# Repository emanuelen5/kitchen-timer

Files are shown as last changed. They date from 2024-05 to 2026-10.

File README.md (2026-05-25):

# Kitchen timer

We're building a Kitchen timer!
The project is heavily inspired by [REST: Kitchen timer by mkdxdx [Hackaday.io]](https://hackaday.io/project/194386-rest-kitchen-timer).

## Features

* ⏱️ Allows several timers to run in parallel
* ⚡ Is battery powered and power efficient
* 🔌 Charged by USB-C
* 💻 Programmable through the same USB port
* 🐍 Easter eggs

## Hardware

* Atmega328P as microcontroller
* Rotary encoder for setting the time
* 16x16 LED matrix as display
* 32 kHz crystal for accurate timekeeping
* Passive buzzer for beeping

See the bill of material in the KiCAD project for the full details.

### Mechanical components

Additionally, you will need the following mechanical components for the assembly:

Description                                               | Qty
--------------------------------------------------------- |-----
Hexagon Socket Button Head Screw ISO 7380-1 - M3 x 16     | 4
Hexagon Socket Button Head Screw ISO 7380-1 - M2 x        | 3
Brass Threaded Insert M3                                  | 4
Brass Threaded Insert M2                                  | 3
Hexagon Socket Button Head Screw ISO 7380-1 - M2 x        | 3
3.7V Lipo battery 1000mAh, 10x20x50mm, JST XH2.54 2 pin   | 1

### Manufacturing / gerber files

If you want to build the PCB yourself, you can download the latest release of Gerber files from Github: <https://github.com/emanuelen5/kitchen-timer/releases/latest>

### Enclosure

The .stl files are available in [./enclosure](./enclosure/) so you can 3D-print the enclosure yourself.

## Software

You can flash the program directly using the ISP header on the board if you want (the same procedure as flashing the bootloader, below). But it's more convenient to add the bootloader so you don't have to open up the enclosure for each software update. Then you can instead program it over the USB-C connector.

For that, you need the bootloader firmware and programmer software which you can download from <https://github.com/emanuelen5/kitchen-timer/releases/tag/bootloader-v1.2.0>.

### Bootloader

To flash the microcontroller with the bootloader, you need `avrdude`.
Avrdude 7.3 can be downloaded from <https://github.com/avrdudes/avrdude/releases/tag/v7.3>. Make sure to add it to your `PATH`.

Connect your programmer of choice to the 6-pin in-system programmer (ISP) connector: \
6-pin ISP header, as viewed from the top
<!--
Attribution:
["6- and 10-pin AVR ISP headers"](https://en.wikipedia.org/wiki/In-system_programming#/media/File:Isp_headers.svg)
by osiixy (2013-01-05), used under [CC BY 3.0](https://creativecommons.org/licenses/by/3.0/).
Adaptations: removed 10-pin header and some text; improved the contrast for dark
             mode.
-->

Then run the following command (replace `<programmer>` with your programmer of choice, like `usbtiny`):

```bash
# the bootloader.hex file needs to be in the current directory
avrdude -p atmega328p -c <programmer> -U flash:w:bootloader.hex:i \
  -U lfuse:w:0x62:m -U hfuse:w:0xD0:m -U efuse:w:0xFF:m
```

> [!TIP]
> Use `avrdude -c ?` to see which programmers are available

This flashes the bootloader and sets the required fuses for the bootloader.

After that you can disconnect the programmer and assemble the device.

### Programmer

Now that you have the bootloader on the device, you can use the USB-C cable for programming it by using the programmer application.

#### Dependencies

First you will need to install some packages that the programmer needs (files from <https://github.com/emanuelen5/kitchen-timer/releases/tag/bootloader-v1.2.0>).

```bash
pip install -r ./programmer/requirements.txt
```

You can now program the application onto the device through the bootloader!

### Upload firmware

Download the latest revision of the firmware (if you want to build it yourself, see [#Development](#development) below) from the releases <https://github.com/emanuelen5/kitchen-timer/releases>.

Connect the USB cable to the device, and then run

```bash
python3 ./programmer/programmer.py --hexfile firmware.hex
```

## Development

### Firmware

To build the firmware, you need `pio` which can be downloaded from <https://pypi.org/project/platformio/> or installed using `pip` (the official Package Installer for Python)

To build any of the environments, use the `pio` command, like

```bash
# builds the main application and puts it in .pio/builds/application/firmware.hex
pio run -e application
```

Then use the programmer to upload the firmware to the device.

## Background

Our kitchen timer is an iteration of [mkdxdx](https://hackaday.io/mkdxdx) project "REST: Kitchen timerREST: Kitchen timer". We wanted to keep the "dial" (rotate-to-set) concept and the 16x16 led matrix but do it with an ATmega328p and a custom PCB.
In the end we scrapped the dial since the design became too complicated, and settled on a simpler design.

### Motivation

Both [Erasmus Cedernaes](https://github.com/emanuelen5) and [Nicolas Perozzi](https://github.com/nperozzi) belong to [Stockholm Makerspace](https://www.makerspace.se/). On the same day, we messaged each other a link to mkdxdx project. We were very excited about building something that would be "practical" so we decided to team up and work on this together. Additionally, we share an interest in working with the AVR MCUs. This project is a nice blend of programming, electrical, mechanical, 3d printing, and design but, without feeling overwhelming.

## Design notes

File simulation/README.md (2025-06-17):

# Firmware simulation with Simavr

To connect to the simulator, do the following:

## Build Simavr simulation program

> [!NOTE]
> You must have built the bootloader firmware first!
> ```bash
> pio run -e bootloader
> ```

Then you can build the simulator

```bash
make
```

Run the simulator

```bash
build/simulator ../.pio/build/bootloader/firmware.hex
```

### Debug

If you pass the `-d` flag to the simulator, it will start a gdb debug server that you can attach to.

Then you can start a debug session with either
  1. From the VScode GUI <br>
     By using the launch configuration called "Attach to AVR gdbserver".
  2. From the command line <br>
     ```bash
     avr-gdb .pio/build/bootloader/firmware.elf
     ```
     And then run `target remote :1234` to attach to the debug session.

## License

This simulator uses Simavr, which is licensed as GPL-3.0. Thus, the whole
simulator is also licensed as GPL-3.0.

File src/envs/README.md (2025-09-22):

# Software

The software is divided into several "environments", similar to "sketches" in Arduino. They are used to test different aspects of the hardware individually, to make sure that the assembled hardware works as intended.

To build an environment, use `pio run -e <environment>`.

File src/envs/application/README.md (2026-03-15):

# Application Environment

## Purpose

Tests the full application layer with all hardware components working together: the LED matrix display, rotary encoder, push button, RTC, buzzer, and UART serial interface.

## Hardware Requirements

- 16×16 LED matrix driven by MAX72xx ICs via SPI (pins PB0, PB2, PB3, PB5)
- Rotary encoder connected to PD2 (channel A) and PD3 (channel B)
- Encoder push button connected to PD4 (SW_PIN)
- 32 kHz crystal connected to TOSC1/TOSC2 (for 1 Hz RTC tick)
- Passive buzzer connected to the buzzer output pin
- 3-LED binary counter connected to PC0–PC2
- UART serial port

## Expected Outcome

The kitchen timer application runs fully:
- Rotating the encoder sets the timer duration.
- A single button press starts or stops the active timer.
- A double press creates a new timer.
- A long press deletes the current timer.
- The LED matrix renders the timer state and counts down in real time.
- The buzzer sounds when a timer expires.
- Serial commands can be sent over UART to control and inspect the application.

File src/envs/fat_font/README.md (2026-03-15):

# Fat Font Environment

## Purpose

Tests the 16×16 LED matrix display by rendering digits using the "fat font" (6×7 pixels per character).

## Hardware Requirements

- 16×16 LED matrix driven by MAX72xx ICs via SPI (pins PB0, PB2, PB3, PB5)

## Expected Outcome

The LED matrix cycles through the digits 0–9, displaying each one for one second before moving to the next. The cycle repeats indefinitely.

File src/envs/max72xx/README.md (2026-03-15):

# MAX72xx Environment

## Purpose

Tests basic communication with the 16×16 LED matrix by toggling every pixel individually over SPI.

## Hardware Requirements

- 16×16 LED matrix driven by MAX72xx ICs via SPI (pins PB0, PB2, PB3, PB5)

## Expected Outcome

All 256 pixels light up one by one (left-to-right, top-to-bottom), and then turn off in the same order. The sequence repeats indefinitely, confirming that all pixels and the SPI link are working correctly.

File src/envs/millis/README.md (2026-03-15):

# Millis Environment

## Purpose

Tests the millisecond timer interrupt by incrementing the LED counter once per second.

## Hardware Requirements

- 3-LED binary counter connected to PC0–PC2

## Expected Outcome

The LED counter increments at a steady 1 Hz rate (once every 1000 ms), confirming that the timer interrupt is firing correctly.

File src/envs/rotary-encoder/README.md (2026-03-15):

# Rotary Encoder Environment

## Purpose

Tests the rotary encoder and its push button by reflecting the input on the LED counter.

## Hardware Requirements

- Rotary encoder connected to PD2 (channel A) and PD3 (channel B)
- Encoder push button connected to PD4 (SW_PIN)
- 3-LED binary counter connected to PC0–PC2

## Expected Outcome

- Rotating the encoder **clockwise** increments the LED counter.
- Rotating the encoder **counter-clockwise** decrements the LED counter.
- A **single press**, **double press**, or **long press** of the button resets the counter to 0.

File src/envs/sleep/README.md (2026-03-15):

# Sleep Environment

## Purpose

Tests the power-save sleep mode and the RTC (Timer2) 1-second interrupt used to wake the microcontroller.

## Hardware Requirements

- 32 kHz crystal connected to TOSC1/TOSC2 (for the Timer2 asynchronous clock)
- 3-LED binary counter connected to PC0–PC2

## Expected Outcome

The MCU enters power-save sleep and is woken up once per second by the RTC interrupt. On each wake cycle the LED counter increments (in the interrupt handler) and then decrements (back in the main loop), causing a visible oscillation on the LEDs that confirms the sleep/wake cycle is working correctly.

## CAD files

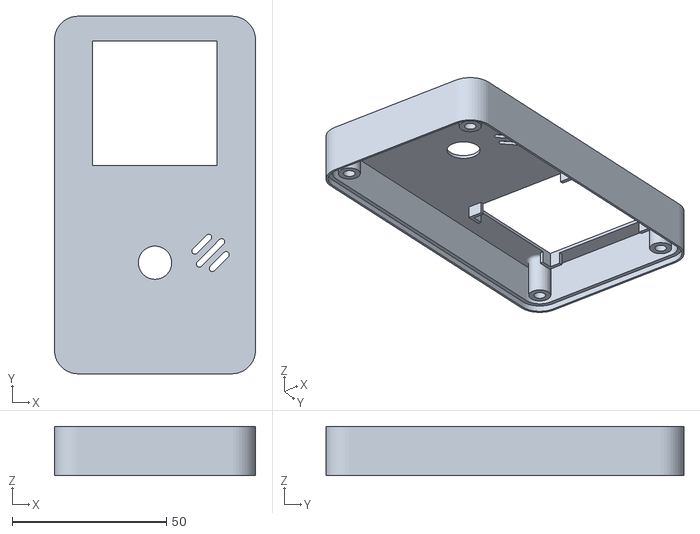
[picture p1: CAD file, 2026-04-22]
enclosure/kitchen_timer-top.stl
65.2 x 116.0 x 15.9

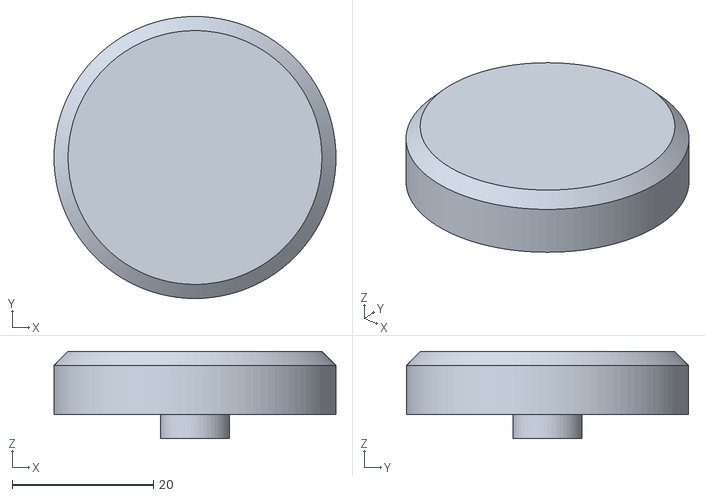
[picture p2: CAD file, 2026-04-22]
enclosure/kitchen_timer-knob.stl
40.0 x 40.0 x 12.4

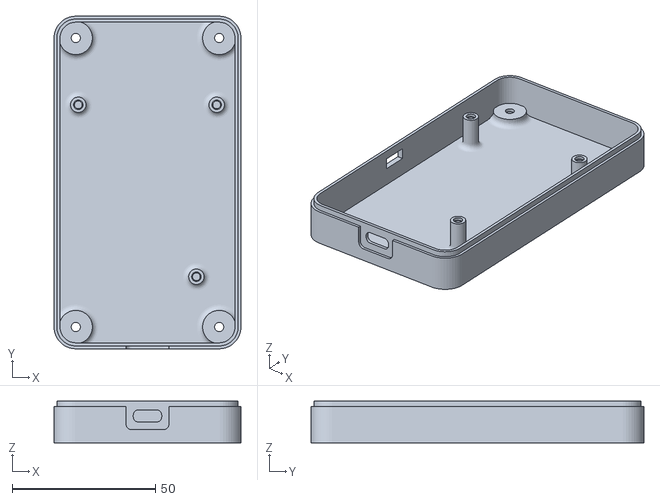
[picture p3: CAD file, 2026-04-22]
enclosure/kitchen_timer-base.stl
65.2 x 116.0 x 14.6

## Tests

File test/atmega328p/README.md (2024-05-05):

# Unit-testing on ATmega328P

This sub-directory contains tests that run on the ATmega328P natively.

## Hook up

To run the unit-tests, you will need to hook up a serial port to the microcontroller.

## Run the tests

To run it, you can use any of the `atmega328p` environments (see the [platformio.ini](../../platformio.ini) file). E.g.

```bash
pio test -e timer
```

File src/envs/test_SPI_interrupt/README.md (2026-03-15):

# Test SPI Interrupt Environment

## Purpose

Tests interrupt-driven SPI transfers by repeatedly sending two bytes over the SPI bus.

## Hardware Requirements

- SPI bus (pins PB2, PB3, PB5) with chip select on PB1 (pin 9)
- 3-LED binary counter connected to PC0–PC2 (optional, used for visual feedback)

## Expected Outcome

Every second, two bytes (`0xAA`) are queued and transferred via SPI using the interrupt handler. A logic analyzer or oscilloscope on the SPI lines will confirm that the transfers are happening correctly at 1 Hz.

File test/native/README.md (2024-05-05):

# Unit-testing on the native host

This sub-directory contains tests that can run on the native host, without any hardware connected.

## Run the tests

To run the tests, run the following.

```bash
pio test -e native
```

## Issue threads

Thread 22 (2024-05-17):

The alarm goes off when powered

nperozzi, 2024-05-17:
When you power the timer, the alarm goes off.

emanuelen5, 2024-05-27:
This does not happen for me. I tried:
1. Upload the "state_machine" sketch (revision 3bfb53817fe3359d4c499b4e5b061b1a1200c563)
2. Unplug and plug in the power again

emanuelen5, 2024-09-04:
We haven't seen this problem in a while, so let's close it for now.

Closed 2024-09-04.

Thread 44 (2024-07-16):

Create button library

nperozzi, 2024-07-16:
Yeah, it would have to be put into its own file. A file that just contains the functionality for pressing the button (not anything relating to the rotation). The button can be described as a state machine, and I think that would make it a lot easier to avoid the sneaky edge conditions :)

But either way, I think we should do this in a follow-up PR. This is definitely good enough for now!

I started a sketch on the state diagram, but it became a mess. I'll have to get back to it. Leaving it here for now:

```mermaid
stateDiagram-v2
    state if_state1 <<choice>>
    state if_state2 <<choice>>

    [*] --> EvaluateSinglePress: PRESS
    EvaluateSinglePress --> SinglePress: [time_since_init < 500 ms] DEPRESS
    EvaluateSinglePress --> LongPress: [time of state > 2000 ms]

    state EvaluateSinglePress {
        [*] --> S1_Wait: [time_since_init <= 500 ms] DEPRESS
    }
    EvaluateSinglePress --> if_state1
    if_state1 --> SinglePress: [time_since_init > 500ms]
    if_state1 --> EvaluateDoublePress: [time_since_init <= 500ms]

    state EvaluateDoublePress {
        [*] --> S2_Wait1: [time_since_init <= 500ms] PRESS
        S2_Wait1 --> S2_Wait2: [time_since_init <= 500ms] DEPRESS
    }
    EvaluateDoublePress --> if_state2
    if_state2 --> DoublePress: [time_since_init <= 500ms] PRESS
    if_state2 --> SinglePress: [time_since_init > 500 ms] PRESS
    if_state2 --> [*]: [time_since_init > 500 ms] DEPRESS

    SinglePress --> [*]
    DoublePress --> [*]
    LongPress --> [*]
```

_Originally posted by @emanuelen5 in https://github.com/emanuelen5/kitchen-timer/pull/41#discussion_r1678366517_

Closed 2024-10-06.

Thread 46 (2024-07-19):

Application Layer

nperozzi, 2024-07-19:
The idea of the `timer_t` class was that it should be as simple as possible. That way we wouldn't need to update it, and its unit tests would still hold.

With more state (variables) added to the object, it becomes more complex and more difficult to test. The tests we've already created do not help as much. And the object doesn't do **only** what was initially intended anymore (just keeping time). This is a code smell:
> Large Class - Class trying to do too much and has too many instance variables[^1]

[^1]: https://refactoring.guru/smells/large-class

I think it would be wiser to try to add another layer of state, an application state:

```mermaid
classDiagram
    class application_t {
        state_machine_t state_machines[MAX_TIMERS]
        uint8_t current_timer_index
    }
    application_t --> state_machine_t

    class state_machine_t {
        state_t state
        timer_t timer
        uint16_t millis_of_last_transition
    }
    state_machine_t --> timer_t

    class timer_t {
        uint16_t original_time
        uint16_t current_time
    }

```

The application would manage what timer is active, and what to show on the display. Adding an abstraction like that even makes it easier to test!

_Originally posted by @emanuelen5 in https://github.com/emanuelen5/kitchen-timer/pull/42#discussion_r1678294955_

nperozzi, 2024-07-19:
After a failed attempt to write the application layer, we agreed it would be best to decide how it should look before I start writing some code 😅 .
This issue aims to do that: agree on what the application layer should do and what the structure should look like before I start writing.

nperozzi, 2024-07-19:
From our conversation yesterday, this is what I understand:
### What should that application layer do?
* Handling the display logic: It decides what state machine is displayed at a given time.
* Decides which state machine gets affected by each event. Example 1: a SINGLE_PRESS would affect only the state machine displayed (current_state_machine) but not the others. Example 2: the SECON_TICK affects all state machines in a RUNNING state.

### Other considerations:
* The application layer is not another state machine. It does not handle states.
* When a state machine goes into state RINGING, it can have a flag that informs the application that it needs to become the current state machine and be displayed.
* The debugging `printf` can remain in the state machines. If a variable within the application struct is needed in the printf (for example `current_state_machine_index`, the application can be passed to the state_machine as a call-back ( following the principle of  "Dependency Inversion")
* Keep the "Law of Demeter" in mind: "Objects only talk directly to their immediate objects" Otherwise, to retrieve information, a function needs to be created.

While writing this, I think how much I may have misinterpreted 🤣.

Closed 2024-08-17.

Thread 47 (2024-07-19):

README files

nperozzi, 2024-07-19:
NOTE: Now that I know that we can discuss topics as Issues, I will go nuts with the issues 😀 !!!

This issue is to discuss how to structure the README files. We talked about it once but I have little space in my memory so I forgot 😓 .

This is how I think we can structure README files (Largely inspired in [kinx project](https://github.com/kinx-project/kint?tab=readme-ov-file) and ChatGPT suggestions):
## Main README:
1. Introduction:
    1. Quick Description
    1.  Motivation
    1.  Features
1. Table of content
1. Software
     1. Description: Brief overview of the software component.
     1. Requirements: Dependency from software versions or external libraries
     1. How to set up the toolchain?
     1. How to install the firmware?
     1. Debugging instructions
1. Hardware
     1. Description: Overview of the hardware components
     2. Hardware BOM
     3. Schematics
     4. Assembly instructions
1. Mechanical
     1. Description: Overview of mechanical components and design.
     2. CAD Files: Links to or images of CAD designs.
     3. Assembly Instructions: Instructions for assembling the mechanical parts.
1. Usage
     1. Power on
     2. Setting timers
     3. ...
     4. Other features
     5. Command prompt

## README file in each library folder:
1. Title
2. What is this library used for?
3. API Reference: Description of functions and objects provided by the library.
4. Configuration: Any configuration variable that the library supports (ex: max number of state machines)
5. Usage: How to implement the library in a generic main file (maybe an example too)

nperozzi, 2024-07-22:
One more note: If we have a README file for each library, shouldn´t we separate the libraries into folders?

emanuelen5, 2024-07-23:
> One more note: If we have a README file for each library, shouldn´t we separate the libraries into folders?

I don't think we need a README for each library. Most of them are easy to understand since they have code that references them. However, I do think that we should explain the sketches / envs, since we need to describe what the minimal setup is required for testing each one of them, and what the expected outcome is.

As a note: We had the libraries in separate folders a while back. But, in 6de6451610f1a4197224e9a18b1edc7b60533f7a I decided that we didn't really benefit from having two files in each folder, with the same name (like `lib/timer/timer.cpp` and `lib/timer/timer.h`).

nperozzi, 2024-07-23:
Understood: no README for libraries but yes for the sketches/envs. 👍😄

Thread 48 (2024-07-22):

SPI communication between display and MCU

nperozzi, 2024-07-22:
I want to make the communication between the display and the MCU SPI since MAX7219 supports it. I believe we talked about it and you agreed. Unfortunately, I believe that it will require some changes in the max72xx library and display library that you already created.
I have started a branch to work on this: [SPI_Max72xx library](https://github.com/emanuelen5/kitchen-timer.git)
This is how I am thinking about it:
* __SPI library__: just to initialize the SPI and a function to transmit a byte.
* __max72xx library__: to initialize the max7219 and functions to write to the registers

With the above, I believe this issues can be closed but, it got me thinking on the following two libraries. I can open a separate issue for this part, if that is ok.
* __display library__: to initialize and write to all max7219. This library should include a function that parses the patterns (numbers and other patterns) to the display.
* __patterns library__: to store the different patterns that can be displayed.

emanuelen5, 2024-07-23:
Just to clarify, it is already using SPI to the display, just not the hardware block in the MCU. By switching to this, we can free up lots of CPU cycles, which is great!

Related PR note: https://github.com/emanuelen5/kitchen-timer/pull/29#issue-2317580666
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

> [^1]: https://forum.arduino.cc/t/spi-miso-mosi-used-in-sketch-possible-to-re-program-via-external-programmer/492461/8
> [^2]: https://onlinedocs.microchip.com/pr/GUID-EEA42155-A873-46B4-9500-D88617041B0B-en-US-2/index.html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
> [^3]: https://onlinedocs.microchip.com/pr/GUID-EEA42155-A873-46B4-9500-D88617041B0B-en-US-2/index.html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

nperozzi, 2024-07-23:
I think I am stepping on your toes here 😟 . Last night I basically re-wrote your max72xx library when maybe it would suffice with some changes (see [SPI_Max72xx library](https://github.com/emanuelen5/kitchen-timer.git)).
How would you like me to proceed here? Maybe I should let you add the hardware SPI block yourself?

nperozzi, 2024-08-17:
When possible, we should take a look at your max72xx and display libraries. I don´t understand what is happening there.

I am also not sure what you mean by the "SPI block". I am guessing that you mean that the max7219 is receiving SPI but the message is generated by the MCU instead of using the microcontroller´s SPI functionality.

Closed 2024-10-08.

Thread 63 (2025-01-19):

Will the bootloader using the UART interfere with the serial communication commands?

nperozzi, 2025-01-19:

emanuelen5, 2025-01-19:
They will not interfere :) The bootloader will only occupy the serial port until the microcontroller has booted the regular application. Then the regular application will take over the serial port.

Closed 2025-01-19.

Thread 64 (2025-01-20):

The UART Module only provides 500mA.

nperozzi, 2025-01-20:
While working on the schematic, I noticed that the UART Module, has a fuse that prevents over-current and only allows 500mA of current. That could be enough to do battery charging but I fear it might not be enough to power the display when the USB is connected to power.

I want some help reviewing power consumption calculations to confirm if 500mA will not be enough.

If it is not enough, an option could be to discard the UART Module and add the USB-C and USB-to-TTL chip directly on our PCB. That way we could draw as much current from the USB as it can supply. It will be more complex though. Do you have better ideas?

nperozzi, 2025-01-22:
After some investigation, it seems that drawing more than 500mA out of a USB port is not a good idea. Doing so can damage the USB host (aka the USB HW in the laptop).
We still have to answer the question: Do we need more than 500mA?

nperozzi, 2025-07-31:
For an average current draw, we need about 86mA. At current pick, we would be drawing about 1300mA, but the UART module will simply not allow it, and the display would light up at not full brightness.

I am closing this issue.

Closed 2025-07-31.

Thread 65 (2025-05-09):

What should be the track width and the via size?

nperozzi, 2025-05-09:
# Track width:
I used the KiCad Calculator Tool. For an avg. current draw of 85.5mA, as calculated in the schematic (sheet Battery Power Requirements), the signal tracks' width should be 9.69mils (~10mils = 0.254mm).

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

For the power nets, I used the peak current draw of 1278.5mA. In this case, the power track width should be at least 16.9mils (~17mil = 0,43mm).

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

#Via size
We are using a via size of 0.7mm in diameter and 0.3mm hole. We got this value from "Philip´s Lab" Youtube Channel.
We used the KiCad Calculator Tool. The resistance, voltage drop, and power loss seem negligible for this via size.

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

nperozzi, 2025-05-09:
- [ ]  We need to adjust the track size for power.

emanuelen5, 2025-05-10:
Great! So neither of the tracks are under-dimensioned as it is. Having a larger power track is also better, even if we would make do with a smaller one.

> We are using a via size of 0.7mm in diameter and 0.3mm hole

We're actually using 0.8 mm since the DRC didn't like the annealing width when it was set to 0.7:

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

Sounds like we don't have to make any adjustments?

emanuelen5, 2025-05-10:
It looks like you used 855mA in your calculation, not 85.5?

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

nperozzi, 2025-05-11:
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

You are right. It was a mistake. Here is the calculation with 85.5mA. It is way smaller in width, so we are good anyway. :)

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

Closed 2025-07-31.

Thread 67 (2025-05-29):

How to make the timers be in RING state no more than a fixed period of timer (maybe just 20 secs)?

nperozzi, 2025-05-29:
Do we need another state?
Could we use the TIMEOUT state?

nperozzi, 2025-07-31:
We solved this by tracking the time that the timer has been in RINGING state, in the `service_state_machine()` function.

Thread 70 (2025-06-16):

Test poin traces is too thin

nperozzi, 2025-06-16:
The +5V test point should have a thicker trace.

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

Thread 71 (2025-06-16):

UART USB powers the MCU with the power switch OFF

nperozzi, 2025-06-16:
When connecting the UART to USB, the MCU appears to receive power even though the power switch is off.

State when the power switch is OFF:
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

State when the power switch is ON:

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

emanuelen5, 2025-07-05:
The MCU becomes back-powered through the RX pin that the USB-UART device drives high when it's idle. See this post for a potential solution: https://electronics.stackexchange.com/a/616357

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

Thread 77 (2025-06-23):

Hole H7 is too close to the trace.

nperozzi, 2025-06-23:
As it is, it works, but the trace is dangerously close to the hole. We should consider moving the hole.

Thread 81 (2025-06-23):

Disabling interrupts durign rtc ISR rutine.

nperozzi, 2025-06-23:
When we disable interrupts on the rtc ISR routine, the program (as seen on the display) does not glitch. If we take the sei() away, it glitches. We do not know why.
Adding "nop()"s does not seem to fix it.

emanuelen5, 2025-07-31:
Yes, let's do that

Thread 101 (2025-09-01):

The device resets when it is disconnected from the computer.

nperozzi, 2025-09-01:

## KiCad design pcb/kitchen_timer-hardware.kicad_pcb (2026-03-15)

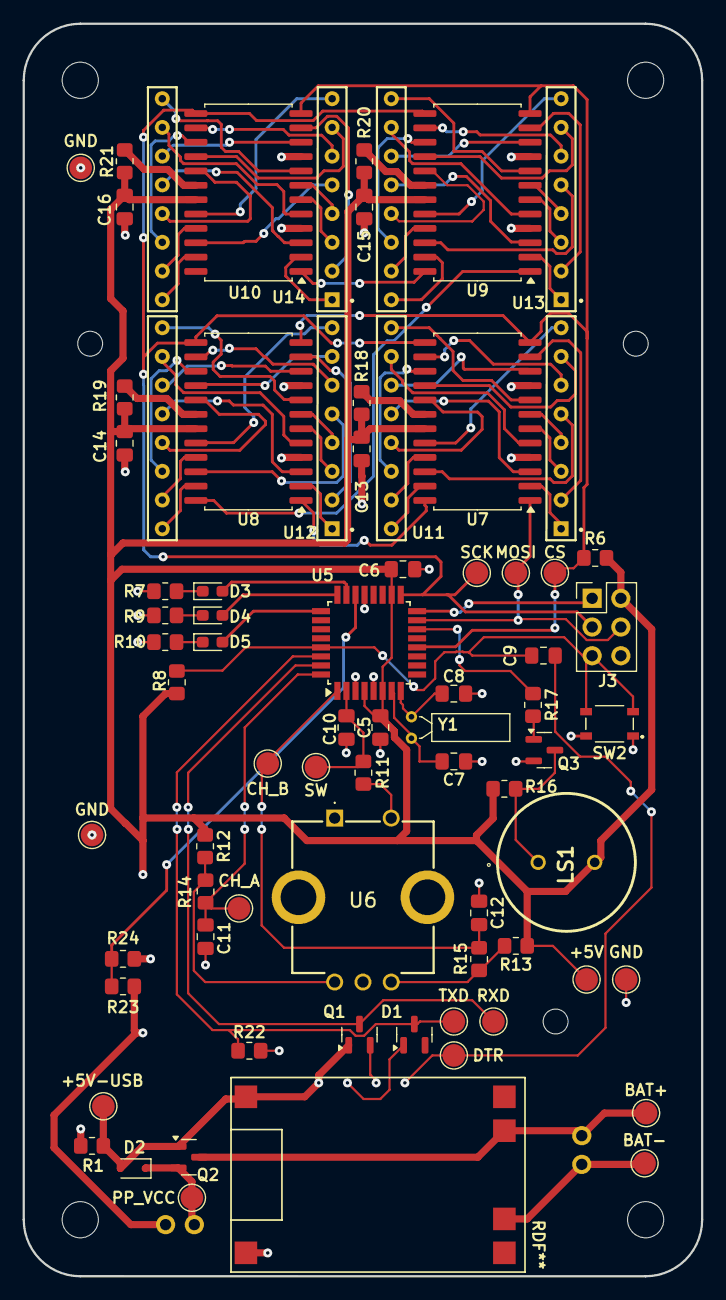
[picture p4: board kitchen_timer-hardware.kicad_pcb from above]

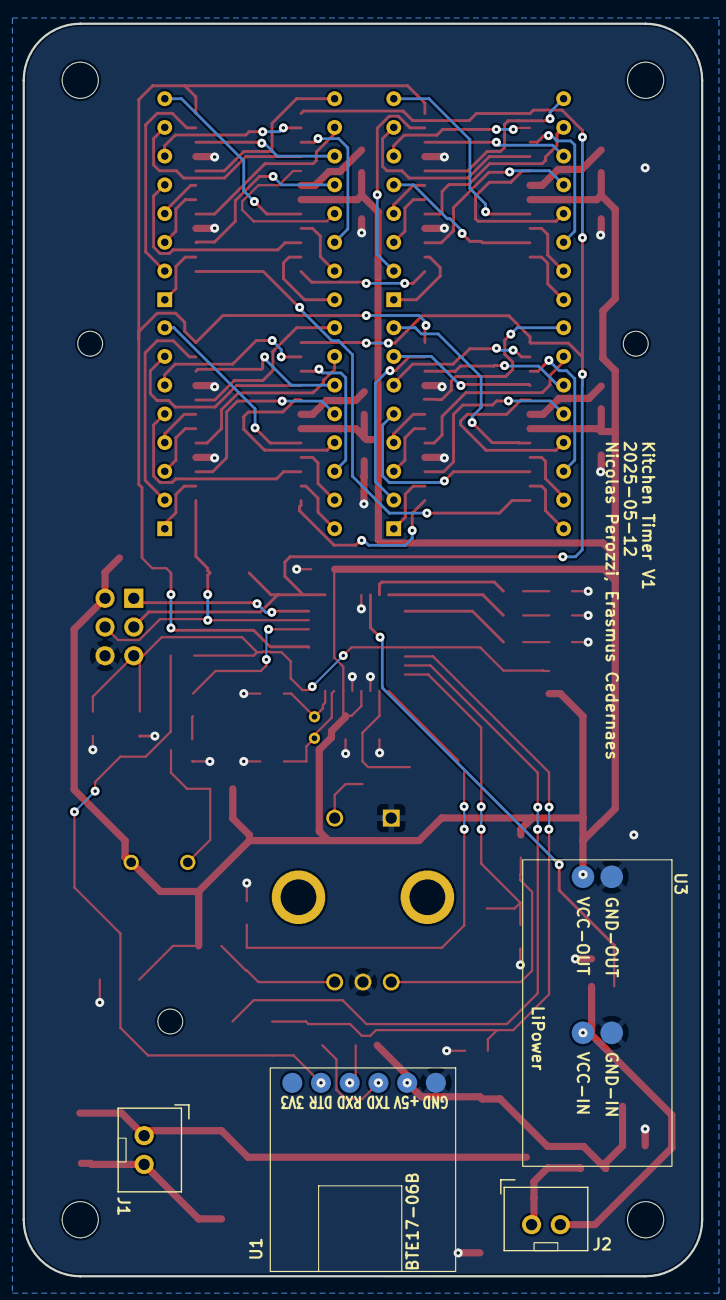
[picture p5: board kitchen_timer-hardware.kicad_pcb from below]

Board: 2 copper layers, 60.0 x 110.8 mm, 83 parts (4 on the bottom side), 106 nets.

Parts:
C5, C6, C9, C13, C14, C15, C16: 100nF; C_0805_2012Metric_Pad1.18x1.45mm_HandSolder
C7, C8: 22pF; C_0805_2012Metric_Pad1.18x1.45mm_HandSolder
C10, C11, C12: 10nF; C_0805_2012Metric_Pad1.18x1.45mm_HandSolder
D1: BAS40; SOT-23
D2: PMEG4010CEJ; D_SOD-323F
D3, D4, D5: Red test LED; LED_0603_1608Metric_Pad1.05x0.95mm_HandSolder
H1, H2, H7: MountingHole; MountingHole_2.2mm_M2
H3, H4, H5, H6: MountingHole; MountingHole_3.2mm_M3
J1: Conn_01x02; JST_XH_1x02_P2.54mm_Vertical
J2: Conn_01x02_Pin; JST_XH_1x02_P2.54mm_Vertical
J3: AVR-ISP-6; PinHeader_2x03_P2.54mm_Vertical
LS1: PS1240P02CT3; PS1240P02BT
Q1: JSM2302; SOT-23
Q2: IRLML6402; SOT-23
Q3: MMBT3904; MMBT3904 (SOT-23)
R1, R6, R8, R11, R12, R13, R14, R15, R22: 10k; R_0805_2012Metric_Pad1.20x1.40mm_HandSolder
R7, R9, R10, R16, R17: 1k; R_0805_2012Metric_Pad1.20x1.40mm_HandSolder
R18, R19, R20, R21: 62K; R_0805_2012Metric_Pad1.20x1.40mm_HandSolder
R23: 3.3M; R_0805_2012Metric_Pad1.20x1.40mm_HandSolder
R24: 1M; R_0805_2012Metric_Pad1.20x1.40mm_HandSolder
SW2: SKRPACE010; SW_SKRPACE010
TP1: MOSI; TestPoint_Pad_D2.0mm
TP2: TXD; TestPoint_Pad_D2.0mm
TP3: SCK; TestPoint_Pad_D2.0mm
TP4: RXD; TestPoint_Pad_D2.0mm
TP5: CS; TestPoint_Pad_D2.0mm
TP6: DTR; TestPoint_Pad_D2.0mm
TP7: +5V-USB; TestPoint_Pad_D2.0mm
TP8, TP14, TP15: GND; TestPoint_Pad_D2.0mm
TP9: CH_A; TestPoint_Pad_D2.0mm
TP10: CH_B; TestPoint_Pad_D2.0mm
TP11: SW; TestPoint_Pad_D2.0mm
TP12: +5V; TestPoint_Pad_D2.0mm
TP13: PP_VCC; TestPoint_Pad_D2.0mm
TP16: BAT+; TestPoint_Pad_D2.0mm
TP17: BAT-; TestPoint_Pad_D2.0mm
U1: CH340E UART Module; CH340E_UART_BREAKOUT
U2: TP4056 breakout; TP4056_BREAKOUT
U3: SparkFun_LiPower
U5: ATMEGA328P-AU; TQFP-32_7x7mm_P0.8mm
U6: PEC11R-4215F-S0024; PEC11R4215FS0024
U7, U8, U9, U10: MAX7219; SOIC-24W_7.5x15.4mm_P1.27mm
U11, U12, U13, U14: KWM-20882CUYB
Y1: Crystal-32kHz; Crystal_C26-LF_D2.1mm_L6.5mm_Horizontal

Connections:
+5V: C5.1, C6.1, C13.1, C14.1, C15.1, C16.1, J3.2 (VCC), LS1.2, R6.1, R8.1, R12.1, R13.1, R16.2, R18.1, R19.1, R20.1, R21.1, TP12.1, U3.3 (VCC_OUT), U5.4 (VCC), U5.6 (VCC), U5.18 (AVCC), U7.19 (V+), U8.19 (V+), U9.19 (V+), U10.19 (V+)
/+5V Boost Converter/BAT_VOLT: R23.2, R24.1, U5.22 (ADC7)
/+5V Boost Converter/PP_VCC: D2.1 (K), J2.1, Q2.2 (S), TP13.1
/BMS & Power Path/+5V-USB: D2.2 (A), Q1.1 (G), Q2.1 (G), R1.2, TP7.1, U1.5 (+5V), U2.1 (IN+)
/BMS & Power Path/BAT+: J1.1, Q2.3 (D), TP16.1, U2.4 (B+)
/BMS & Power Path/BAT-: J1.2, TP17.1, U2.5 (B-)
/LED Matrices Drivers/CS: R6.2, TP5.1, U5.12 (PB0), U7.12 (LOAD), U8.12 (LOAD), U9.12 (LOAD), U10.12 (LOAD)
/LED Matrices Drivers/MOSI: J3.4 (MOSI), TP1.1, U5.15 (PB3), U7.1 (DIN)
/LED Matrices Drivers/Mat1A.DIG_0: U7.2 (DIG_0), U11.01 (R1)
/LED Matrices Drivers/Mat1A.DIG_1: U7.11 (DIG_1), U11.02 (R2)
/LED Matrices Drivers/Mat1A.DIG_2: U7.6 (DIG_2), U11.03 (R3)
/LED Matrices Drivers/Mat1A.DIG_3: U7.7 (DIG_3), U11.04 (R4)
/LED Matrices Drivers/Mat1A.DIG_4: U7.3 (DIG_4), U11.12 (R5)
/LED Matrices Drivers/Mat1A.DIG_5: U7.10 (DIG_5), U11.11 (R6)
/LED Matrices Drivers/Mat1A.DIG_6: U7.5 (DIG_6), U11.10 (R7)
/LED Matrices Drivers/Mat1A.DIG_7: U7.8 (DIG_7), U11.09 (R8)
/LED Matrices Drivers/Mat1A.SEG_A: U7.14 (SEG_A), U11.06 (C2)
/LED Matrices Drivers/Mat1A.SEG_B: U7.16 (SEG_B), U11.07 (C3)
/LED Matrices Drivers/Mat1A.SEG_C: U7.20 (SEG_C), U11.08 (C4)
/LED Matrices Drivers/Mat1A.SEG_D: U7.23 (SEG_D), U11.16 (C5)
/LED Matrices Drivers/Mat1A.SEG_DP: U7.22 (SEG_DP), U11.05 (C1)
/LED Matrices Drivers/Mat1A.SEG_E: U7.21 (SEG_E), U11.15 (C6)
/LED Matrices Drivers/Mat1A.SEG_F: U7.15 (SEG_F), U11.14 (C7)
/LED Matrices Drivers/Mat1A.SEG_G: U7.17 (SEG_G), U11.13 (C8)
/LED Matrices Drivers/Mat1B.DIG_0: U8.2 (DIG_0), U12.01 (R1)
/LED Matrices Drivers/Mat1B.DIG_1: U8.11 (DIG_1), U12.02 (R2)
/LED Matrices Drivers/Mat1B.DIG_2: U8.6 (DIG_2), U12.03 (R3)
/LED Matrices Drivers/Mat1B.DIG_3: U8.7 (DIG_3), U12.04 (R4)
/LED Matrices Drivers/Mat1B.DIG_4: U8.3 (DIG_4), U12.12 (R5)
/LED Matrices Drivers/Mat1B.DIG_5: U8.10 (DIG_5), U12.11 (R6)
/LED Matrices Drivers/Mat1B.DIG_6: U8.5 (DIG_6), U12.10 (R7)
/LED Matrices Drivers/Mat1B.DIG_7: U8.8 (DIG_7), U12.09 (R8)
/LED Matrices Drivers/Mat1B.SEG_A: U8.14 (SEG_A), U12.06 (C2)
/LED Matrices Drivers/Mat1B.SEG_B: U8.16 (SEG_B), U12.07 (C3)
/LED Matrices Drivers/Mat1B.SEG_C: U8.20 (SEG_C), U12.08 (C4)
/LED Matrices Drivers/Mat1B.SEG_D: U8.23 (SEG_D), U12.16 (C5)
/LED Matrices Drivers/Mat1B.SEG_DP: U8.22 (SEG_DP), U12.05 (C1)
/LED Matrices Drivers/Mat1B.SEG_E: U8.21 (SEG_E), U12.15 (C6)
/LED Matrices Drivers/Mat1B.SEG_F: U8.15 (SEG_F), U12.14 (C7)
/LED Matrices Drivers/Mat1B.SEG_G: U8.17 (SEG_G), U12.13 (C8)
/LED Matrices Drivers/Mat2A.DIG_0: U9.2 (DIG_0), U13.01 (R1)
/LED Matrices Drivers/Mat2A.DIG_1: U9.11 (DIG_1), U13.02 (R2)
/LED Matrices Drivers/Mat2A.DIG_2: U9.6 (DIG_2), U13.03 (R3)
/LED Matrices Drivers/Mat2A.DIG_3: U9.7 (DIG_3), U13.04 (R4)
/LED Matrices Drivers/Mat2A.DIG_4: U9.3 (DIG_4), U13.12 (R5)
/LED Matrices Drivers/Mat2A.DIG_5: U9.10 (DIG_5), U13.11 (R6)
/LED Matrices Drivers/Mat2A.DIG_6: U9.5 (DIG_6), U13.10 (R7)
/LED Matrices Drivers/Mat2A.DIG_7: U9.8 (DIG_7), U13.09 (R8)
/LED Matrices Drivers/Mat2A.SEG_A: U9.14 (SEG_A), U13.06 (C2)
/LED Matrices Drivers/Mat2A.SEG_B: U9.16 (SEG_B), U13.07 (C3)
/LED Matrices Drivers/Mat2A.SEG_C: U9.20 (SEG_C), U13.08 (C4)
/LED Matrices Drivers/Mat2A.SEG_D: U9.23 (SEG_D), U13.16 (C5)
/LED Matrices Drivers/Mat2A.SEG_DP: U9.22 (SEG_DP), U13.05 (C1)
/LED Matrices Drivers/Mat2A.SEG_E: U9.21 (SEG_E), U13.15 (C6)
/LED Matrices Drivers/Mat2A.SEG_F: U9.15 (SEG_F), U13.14 (C7)
/LED Matrices Drivers/Mat2A.SEG_G: U9.17 (SEG_G), U13.13 (C8)
/LED Matrices Drivers/Mat2B.DIG_0: U10.2 (DIG_0), U14.01 (R1)
/LED Matrices Drivers/Mat2B.DIG_1: U10.11 (DIG_1), U14.02 (R2)
/LED Matrices Drivers/Mat2B.DIG_2: U10.6 (DIG_2), U14.03 (R3)
/LED Matrices Drivers/Mat2B.DIG_3: U10.7 (DIG_3), U14.04 (R4)
/LED Matrices Drivers/Mat2B.DIG_4: U10.3 (DIG_4), U14.12 (R5)
/LED Matrices Drivers/Mat2B.DIG_5: U10.10 (DIG_5), U14.11 (R6)
/LED Matrices Drivers/Mat2B.DIG_6: U10.5 (DIG_6), U14.10 (R7)
/LED Matrices Drivers/Mat2B.DIG_7: U10.8 (DIG_7), U14.09 (R8)
/LED Matrices Drivers/Mat2B.SEG_A: U10.14 (SEG_A), U14.06 (C2)
/LED Matrices Drivers/Mat2B.SEG_B: U10.16 (SEG_B), U14.07 (C3)
/LED Matrices Drivers/Mat2B.SEG_C: U10.20 (SEG_C), U14.08 (C4)
/LED Matrices Drivers/Mat2B.SEG_D: U10.23 (SEG_D), U14.16 (C5)
/LED Matrices Drivers/Mat2B.SEG_DP: U10.22 (SEG_DP), U14.05 (C1)
/LED Matrices Drivers/Mat2B.SEG_E: U10.21 (SEG_E), U14.15 (C6)
/LED Matrices Drivers/Mat2B.SEG_F: U10.15 (SEG_F), U14.14 (C7)
/LED Matrices Drivers/Mat2B.SEG_G: U10.17 (SEG_G), U14.13 (C8)
/LED Matrices Drivers/SCK: J3.3 (SCK), TP3.1, U5.17 (PB5), U7.13 (CLK), U8.13 (CLK), U9.13 (CLK), U10.13 (CLK)
/Microcontroller/DTR: C9.1, TP6.1, U1.2 (DTR)
/Microcontroller/ENCODER_CH_A: C11.1, R14.2, TP9.1, U5.32 (PD2)
/Microcontroller/ENCODER_CH_B: C12.1, R15.2, TP10.1, U5.1 (PD3)
/Microcontroller/MCU_RXD: D1.3 (K), R22.1, TP2.1, U5.30 (PD0)
/Microcontroller/MCU_TXD: Q1.3 (D), TP4.1, U5.31 (PD1)
/Microcontroller/MISO: J3.1 (MISO), U5.16 (PB4)
/Microcontroller/RESET: C9.2, J3.5 (~RST), R8.2, SW2.3, SW2.4, U5.29 (~RESET/PC6)
/Microcontroller/SPEAKER: R17.1, U5.14 (PB2)
/Microcontroller/SW: C10.1, R11.2, TP11.1, U5.2 (PD4)
/Microcontroller/TEST_LED1: D3.2 (A), U5.23 (PC0)
/Microcontroller/TEST_LED2: D4.2 (A), U5.24 (PC1)
/Microcontroller/TEST_LED3: D5.2 (A), U5.25 (PC2)
/Microcontroller/XTAL1: C7.1, U5.7 (XTAL1/PB6), Y1.1
/Microcontroller/XTAL2: C8.1, U5.8 (XTAL2/PB7), Y1.2 (CRYSTAL_2)
GND: C5.2, C6.2, C7.2, C8.2, C10.2, C11.2, C12.2, C13.2, C14.2, C15.2, C16.2, J3.6 (GND), Q3.2 (E), R1.1, R7.2, R9.2, R10.2, R22.2, R24.2, SW2.1, SW2.2, TP8.1, TP14.1, TP15.1, U1.6 (GND), U2.2 (IN-), U3.2 (GND-IN), U3.4 (GND_OUT), U5.3 (GND), U5.5 (GND), U5.21 (GND), U6.1 (COM), U6.C1 (COMMON), U7.4 (GND), U7.9 (GND), U8.4 (GND), U8.9 (GND), U9.4 (GND), U9.9 (GND), U10.4 (GND), U10.9 (GND)
unnamed: D1.1 (A), U1.4 (TXD)
unnamed: D3.1 (K), R7.1
unnamed: D4.1 (K), R9.1
unnamed: D5.1 (K), R10.1
unnamed: Q1.2 (S), U1.3 (RXD)
unnamed: Q3.1 (B), R17.2
unnamed: LS1.1, Q3.3 (C), R16.1
unnamed: R12.2, R14.1, U6.A1 (CHANNEL_A)
unnamed: R13.2, R15.1, U6.B1 (CHANNEL_B)
unnamed: R11.1, U6.2 (NO)
unnamed: U7.24 (DOUT), U8.1 (DIN)
unnamed: R18.2, U7.18 (ISET)
unnamed: U8.24 (DOUT), U9.1 (DIN)
unnamed: R19.2, U8.18 (ISET)
unnamed: R20.2, U9.18 (ISET)
unnamed: U9.24 (DOUT), U10.1 (DIN)
unnamed: R21.2, U10.18 (ISET)
PP_VCC_after_switch: J2.2, R23.1, U3.1 (VCC_IN)

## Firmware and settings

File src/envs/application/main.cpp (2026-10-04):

#include <avr/io.h>
#include <avr/interrupt.h>
#include <avr/pgmspace.h>

#include "util.h"
#include "rtc.h"
#include "millis.h"
#include "uint8-queue.h"
#include "UART.h"
#include "serial_commands.h"
#include "reboot.h"
#include "led-counter.h"

#include "max72xx.h"
#include "avr_button.h"
#include "rotary-encoder.h"
#include "application.h"
#include "render.h"

uint8_queue_t eventQueue;
static const uint8_t queue_buffer_size = 8;
uint8_t event_queue_buffer[queue_buffer_size];

application_t app;
state_machine_t* active_sm = &app.state_machines[app.current_active_sm];

void init_watchdog(void) __attribute__((naked)) __attribute__((section(".init3"))); //desables watchdog before main().

void rotation_cb(rotation_dir_t dir, rotation_speed_t speed, bool held_down)
{
    event_t event;
    if (held_down && dir == cw)
        event = CW_PRESSED_ROTATION;
    else if (held_down && dir == ccw)
        event = CCW_PRESSED_ROTATION;
    else if (!held_down && dir == cw && speed == fast)
        event = CW_ROTATION_FAST;
    else if (!held_down && dir == cw)
        event = CW_ROTATION;
    else if (!held_down && dir == ccw && speed == fast)
        event = CCW_ROTATION_FAST;
    else if (!held_down && dir == ccw)
        event = CCW_ROTATION;

    add_to_queue(&eventQueue, event);
}

void on_single_press(void)
{
    add_to_queue(&eventQueue, SINGLE_PRESS);
}

void on_double_press(void)
{
    add_to_queue(&eventQueue, DOUBLE_PRESS);
}

void on_long_press(void)
{
    add_to_queue(&eventQueue, LONG_PRESS);
}

void second_tick_cb(void)
{
    add_to_queue(&eventQueue, SECOND_TICK);
}


void on_line_received(char *line)
{
    handle_command(line, &command_callbacks, &app);
}

int main()
{
    AvrButton button(&on_single_press, &on_double_press, &on_long_press, &rotation_cb);

    init_hw_UART(on_line_received);
    init_hw_timer2_to_1s_interrupt(&second_tick_cb);
    init_hw_millis();
    init_hw_led_counter();
    init_hw_max72xx();
    init_queue(&eventQueue, event_queue_buffer, queue_buffer_size);
    init_hw_rotary_encoder(button);
    init_application(&app);
    max72xx_set_intensity(app.brightness);
    sei();

    init_max72xx();
    while (true)
    {
        for (uint8_t count = UART_received_char_count(); count != 0; count--)
        {
            service_receive_UART();
        }

        button.service();

        dequeue_return_t event;
        while ((event = dequeue(&eventQueue)).is_valid)
        {
            application_handle_event(&app, (event_t)event.value);
        }
        service_application(&app);

        render(&app);
    }

    return 0;
}

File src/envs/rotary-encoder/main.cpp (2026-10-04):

#include "led-counter.h"
#include "util.h"

#include <avr/io.h>
#include <avr/interrupt.h>
#include <util/delay.h>
#include "millis.h"
#include "rotary-encoder.h"
#include "avr_button.h"

volatile unsigned long last_trigger = 0;

void rotation_cb(rotation_dir_t dir, rotation_speed_t speed, bool held_down)
{
    UNUSED held_down;
    UNUSED speed;
    if (dir == cw)
        increment_counter();
    else if (dir == ccw)
        decrement_counter();
}

void on_single_press(void)
{
    reset_led_counter();
}

void on_double_press(void)
{
    reset_led_counter();
}

void on_long_press(void)
{
    reset_led_counter();
}


int main()
{
    AvrButton button(&on_single_press, &on_double_press, &on_long_press, &rotation_cb);
    init_hw_led_counter();
    init_hw_millis();
    init_hw_rotary_encoder(button);
    increment_counter();
    sei();

    while (true)
    {
        if ((PIND & bit(SW_PIN)) == 0)
        {
            reset_led_counter();
        }
        button.service();
    }

    return 0;
}

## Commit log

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2024-03-23 Create a buzzer environment
    [main.cpp]
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2024-05-04 Add lowpass filter for debouncing the rotary encoder
    [schema.fzz]
2024-05-06 Fix compiler warning: Unused argument
    [tests.cpp]
2024-05-06 Fix compiler warning: Unhandled enumeration value
    [main.cpp]
2024-05-16 Correct the prescaler
    With CS22 and CS20 it becomes /128 prescaler. With just CS22, it was
    just /64 prescaler.
    Also, we had to clear the other register since Arduino overwrites it in
    the init() function, which is called at the start of Arduino's main()
    method.
    [main.cpp]
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2024-05-16 Reduce the software interrupt filter
    It's now solved in hardware
2024-05-21 Add push button as interrupt
    I added the push button using pin-change interrupt. By using pin-change
    interrupt, I avoid using INT1 which we can use for something else.
    [main.cpp]
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2024-05-22 Remove the Arduino framework
    Unfortunately this make toneAC not build anymore, but let's fix that in
    the following commits
2024-05-22 Replace toneAC so we can remove the Arduino FW completely
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2024-05-25 Remove the timer sketch
    It doesn't test anything else than the other sketches
    [main.cpp]
2024-05-26 Add schematic
    I also added two missing ground connections in the schematic while at it.
    [schema.fzz]
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2024-05-28 Add serial port (#18)
    * Make rotary encoder reliable
    * removed a missplaced comment
    * added push button
    I added the push button using pin-change interrupt. By using pin-change interrupt, I avoid using INT1 which we can use for something else.
    * Implemented Timer/Counter2 interrupt overflow
    * changed names to timer.h functions
    I did this to reflect better what variable they were modifying.
    * moved reset_timer function call to inside the init_timer function
    * made the reset_orignial_time to set the original_time to 0
    * modified reset_timer() so it resets bo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
    [main.cpp, tests.cpp]
2024-05-29 Add missing resistor to piezo
    [schema.fzz]
2024-05-29 Add necessary project file to compile with inter-library dependencies
    Without it we got the error
    ```
    Building...
    lib\platform-independent\src\timer.cpp:1:10: fatal error: avr/io.h: No such file or directory
    1 | #include <avr/io.h>
    | ^~~~~~~~~~
    compilation terminated.
    *** [.pio\build\native\libadc\platform-independent\timer.o] Error 1
    ```
2024-06-07 Move timer_t to a namespace
    unity.h had it's own timer_t typedef that collided, so I had to move it to its own namespace to make it work
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2024-07-20 Implement long press (#41)
    * Work in progress. Implementing the button long press functionality.
    * changed bit_is_set for bit_is_clear
    * removed a comment in rotary-encode.cpp and moved a function in the main loop
    * fixed init_rotary_encoder and added a button_long_press_cb function.
    * Implemented double button press
    * Modified state machine to test the double_button_press functionality
    * upadated Rotary-encoder main to pass the tests
    * Re-establish SINGLE_PRESS as the event to PAUSE and terminate RINGING
    * added button struct
    * pre-processor defines, replaced by consts
    * replaced all unsigned long for uint16_t
    * changed long_press_duration_ms to 2000ms
    *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
    [main.cpp]
2024-08-17 Application library (#49)
    * C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
    [main.cpp]
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2024-09-27 Replace button implementation with class
    [main.cpp]
2024-09-27 Replace the link-time implementation with function pointer
    [main.cpp, tests.cpp]
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2024-10-04 Reset press count in handler
    [tests.cpp]
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2024-10-08 Use the SPI hardware block instead of bit-banging (#50)
    * created files SPI.h and SPI.cpp
    * Created SPI_init and SPI_transmit_byte
    * Changed the name of the init SPI function to be consistent with other init functions.
    * Modified max72xx library to use the SPI library.
    I don´t love how the init_maz72xx is looking but this is how I managed to use the max72_com_t struct and the max72xx_reg_t. I am not sure if this was the best way.
    * Changed the send_command function for write_byte. It felt easier to use :)
    * added max72xx_clear function
    * main file to test max72xx library with SPI
    * changed the name of the env folder cause I named it wrongly. This commit also contains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
    [main.cpp]
2024-10-08 Fix ordering of bytes when sent over SPI
    The first byte is sent to the last device, and so on, backwards
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2024-10-11 Move the SS pin to PB0
    This has the advantage that it doesn't collide with the speaker output port, so we can keep that.
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2024-10-21 Keep SPI block in master mode
    This change fixes a bug where the SPI HW module switches from master
    mode whenever the SS pin went low.
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2025-01-20 Added Bootloader auto-reset circuit.
    [kitchen_timer-hardware.kicad_sch]
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2025-01-25 Updated 3.3V Regulator as per the schematic on the Datasheet.
    [kitchen_timer-hardware.kicad_sch]
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2025-01-26 Added the LED Matrices Driers as a hierarchical schematic.
    I used the herachical schmatic feature cause it gives us more space to work on and organize connections.
    [kitchen_timer-hardware.kicad_sch, led_matrices_drivers.kicad_sch]
2025-01-26 Added no_connect marker to the last DOUT on the chain
    [led_matrices_drivers.kicad_sch]
2025-01-26 Added the LED Matrice Display schematic. Added LED Matrix symbol
    [kitchen_timer-hardware.kicad_sch, led_matrices_display.kicad_sch, led_matrices_drivers.kicad_sch]
2025-01-26 Added the values of resostors and caps that for some reason got reseted.
    [3V3_regulator.kicad_sch, 5V_boost_converter.kicad_sch, kitchen_timer-hardware.kicad_sch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]
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2025-01-29 Added components to the UART Module to prevent backfeeding the module when the USB is not connected.
    [kitchen_timer-hardware.kicad_sch, uart_debugger.kicad_sch]
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2025-01-29 Made the global labels for power visible in the main shchematic
    [3V3_regulator.kicad_sch, 5V_boost_converter.kicad_sch, kitchen_timer-hardware.kicad_sch]
2025-01-31 Added some fields on the symbol table to record where to purchase components
    [uart_debugger.kicad_sch]
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2025-02-02 Added information, footprints and 3d models for several components
    [3V3_regulator.kicad_sch, 5V_boost_converter.kicad_sch, led_matrices_display.kicad_sch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]
2025-02-02 Added some information to the microcontroller sch and the power_management sch
    [microcontroller.kicad_sch, power_management.kicad_sch]
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2025-02-03 Added TP4056 footprint andconfirmed components in UART and BMS schematics.
    [microcontroller.kicad_sch, piezo_speaker.kicad_sch, power_management.kicad_sch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]
2025-02-05 Removed the 3.3V Regulator since we might need to run everything out of 5V
    [kitchen_timer-hardware.kicad_sch, led_matrices_display.kicad_sch, microcontroller.kicad_sch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]
2025-03-04 stuff. At this point we decided it is not worth tracking changes on schematics
    [5V_boost_converter.kicad_sch, kitchen_timer-hardware.kicad_sch, led_matrices_display.kicad_sch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]
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2025-04-05 Added filter to SW pin on Rotary Encoder
    [rotary_encoder.kicad_sch]
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2025-04-09 Added comments to the TODO boxes after the meeting with Erasmus
    [boost_converter.kicad_sch, kitchen_timer-hardware.kicad_sch, piezo_speaker.kicad_sch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]
2025-04-09 Changed from an Active to a Passive buzzer. This will allow us to make tones with a PWM singal
    [piezo_speaker.kicad_sch]
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2025-04-11 Removed comments on UART, added some footprints and started fixing rule checks
    [boost_converter.kicad_sch, kitchen_timer-hardware.kicad_sch, led_matrices_display.kicad_sch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]
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2025-04-13 Added many footprints and populated part of the property tables
    [boost_converter.kicad_sch, led_matrices_display.kicad_sch, led_matrices_drivers.kicad_sch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]
2025-04-14 Completed the property teble except for the cyristal oscilator
    [boost_converter.kicad_sch, kitchen_timer-hardware.kicad_sch, led_matrices_display.kicad_sch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]
2025-04-19 Made some small changes on the properties of some components while having last weeks meeting and added the fp-info-cache to the gitignore file
    [boost_converter.kicad_sch, led_matrices_display.kicad_sch, microcontroller.kicad_sch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]
2025-04-19 My Kicad seem to have missed some changes on the led matrices drivers which are being updated here
    [led_matrices_drivers.kicad_sch]
2025-04-19 Removed the extra components on the bootloader auto-reset
    [microcontroller.kicad_sch]
2025-04-20 Replaced the power switch for a two pin connector. Changed the boost converter design to convert to 5V again. Added a comple files to .gitignore.
    [boost_converter.kicad_sch]
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2025-04-22 Added footprints to mounting holes and selected a part for the test LED.
    [boost_converter.kicad_sch, kitchen_timer-hardware.kicad_pcb, kitchen_timer-hardware.kicad_sch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]
2025-04-22 Made some items DNP and/or Exclude form Board
    [boost_converter.kicad_sch, piezo_speaker.kicad_sch, power_management.kicad_sch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]
2025-04-22 Added a pull up resistor to the CS line on the SPI and added two more test LEDs
    [boost_converter.kicad_sch, kitchen_timer-hardware.kicad_sch, led_matrices_display.kicad_sch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]
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2025-04-28 Joint review with Nicolas
    Changes in placement of components:
    - Rotated uC 90 degrees clockwise to make it easier to route programmer
    header
    - Rotated screens 180 degrees to get close to uC's MOSI pin
    - Moved in some mounting holes (temporary until we have fixed the size)
    - Some other small changes in placement
    [kitchen_timer-hardware.kicad_pcb]
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2025-04-29 Changed the footprint of the crystal for one were the crystal is horizontal.
    [kitchen_timer-hardware.kicad_pcb, microcontroller.kicad_sch]
2025-04-29 Changed the J2 connector for the same one as the J1
    [boost_converter.kicad_sch, kitchen_timer-hardware.kicad_pcb]
2025-04-29 Added 3d models for the matrices and removed holes on the UART breakout footprint.
    [kitchen_timer-hardware.kicad_pcb]
2025-04-29 Removed the power switch symbol form the schematic. It was adding an undefined net and hiding the connection between the boost converter and the power path.
    [boost_converter.kicad_sch]
2025-04-29 Put the mounting holes in place and aligned components.
    [kitchen_timer-hardware.kicad_pcb, kitchen_timer-hardware.kicad_sch]
2025-04-29 Moved buzzer to prevent a colition.
    [kitchen_timer-hardware.kicad_pcb]
2025-04-29 Made the encoder and the buzzer 3d models visible.
    [kitchen_timer-hardware.kicad_pcb]
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2025-04-30 I shorten the leads on the buzzer 3d model
    [kitchen_timer-hardware.kicad_pcb]
2025-05-03 I routed the display, added the SPI Test Points. Before calling it a day, I runned Rules Check and fixed all the issues related to display routing, text size and some issues with the footprints.
    [kitchen_timer-hardware.kicad_pcb, uart_debugger.kicad_sch]
2025-05-04 Move connectors a lot closer to their use
    [kitchen_timer-hardware.kicad_pcb]
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2025-05-05 Rotate BMS and add some small adjustments to fix some DRC issues
    [kitchen_timer-hardware.kicad_pcb]
2025-05-07 Search/replace via size to adhere to JLCPCB fabrication rules
    Down from 130 to 85 DRC rules now
    [kitchen_timer-hardware.kicad_pcb]
2025-05-10 Fix all DRC errors relating to vias and traces
    Still 49 errors regarding footprints and silkscreen
    [kitchen_timer-hardware.kicad_pcb]
2025-05-10 Change 20 mil tracks to 25 mil
    Most were 25 mil already.
    [kitchen_timer-hardware.kicad_pcb]
2025-05-10 Fix silscreen DRC errors
    Down to 8 DRC errors now
    [kitchen_timer-hardware.kicad_pcb]
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2025-05-12 Remvoed the reference lable from one hole that I missed
    [kitchen_timer-hardware.kicad_pcb]
2025-05-13 Reviewed the Fields Table and marked all components that should not be populated. Then I runned rules check in the schematic and PCB
    [boost_converter.kicad_sch, kitchen_timer-hardware.kicad_pcb, kitchen_timer-hardware.kicad_sch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]
2025-05-13 I created the gerber files, the placement file, the drill file and the BOM. I know we said that we were going to upload this files as a release but I did not wanted to lose the changes. We can make t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
    [kitchen_timer-hardware-BOM.csv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]
2025-05-25 These are the changes we did to the files when we ordered the PCBs. Here is the zip file, changes to the BOM, components positions and saved table view for the BOM file.
    [kitchen_timer-hardware-BOM.csv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]
2025-06-07 Bootloader simulator (#59)
    * Add simavr simulator
    * Remove some redundant headers
    * Move avr object into main
    * Remove vcd
    * Use fuse values for bootloader
    * Extract predicate
    * Use getopts to parse arguments
    Break out argument parsing into a function
    * Ignore flash image run output
    * Add debug configuration for running with vscode
    * Rename the simulator
    * Create Github action for building
    * Move UART usages closer to each other
    * Break out function for filling flash with main program
    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
    [graphics.cpp, main.cpp, simulator.cpp]
2025-06-07 Test some more error modes
    [tests.cpp]
2025-06-07 Skip calculating checksum while receiving
    It's too slow to do in the middle
    [main.cpp]
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2025-06-08 Fix bug in state machine
    [main.cpp]
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2025-06-14 Account for auto-reset through DTR pin
2025-06-14 Fix expected number of bytes to receive
    This improves the speed of the protocol significantly since we don't
    have to wait until the read command times out.
    Benchmark before:
    - time between packets: 400-450 ms
    - total time to flash millis: 3.1 s
    Benchmark after:
    - time between packets: 20-30 ms (~17x speedup)
    - total time to flash millis: 630 ms (~5x speedup)
2025-06-14 Fix error in fd324042d81879f6b02a9b8ec7e472f4df821155
    The order of the arguments was switched up
    [main.cpp, tests.cpp]
2025-06-14 Fix rotation of x/y after testing on rev 1 board
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2025-06-28 Don't implicitly reset buffer
    The buffers are reset at initialization either way.
    If the device for some reason spits out random bytes when booting, we
    might want to handle that somewhere, but in that case it should be more
    explicit about it.
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2025-07-01 Fixed bug where initializing millis.h would interfere with the SPI
2025-07-01 I blocked interrupts during the rtc ISRto prevent the timer to crash.
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2025-07-03 Fix erase logic
    The bootloader only worked the first time it was used, since the flash
    was empty at that point. The next time it was used, bits weren't
    properly reset to 0xFF, so the written firmware would become AND:ed with
    the previous firmware...
    [main.cpp]
2025-07-03 Remove LED counter
    It made the code too slow, which caused the bootloader to not have time
    to receive data.
    [main.cpp]
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2025-07-17 Fixed render_timer_view/main.cpp which was not working
    [main.cpp]
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2025-07-23 Fixed bug with the Timers Indicator column
    [main.cpp]
2025-07-23 Made the press rotation skip timers that are in IDLE state.
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2025-07-26 Fixed compiling error on render_timer_view
    [main.cpp]
2025-07-26 Fixed a broken test
    [tests.cpp]
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2025-09-12 Fix 'press, then rotate' bug
    When pressing and then rotating in short sequence, it would sometimes
    not register the first press, unless you waited for a long time between
    them.
    Fixes #96
    [tests.cpp]
2025-09-12 Fix bug where timer wraps below zero
    Fixes #94
    [tests.cpp]
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2025-09-13 Shorten time before starting main application to ~0.6 secondds
    [main.cpp]
2025-09-14 Clean up toneAC and make less generalized
    We have no use of those things, and they just take up storage space
    (plus an unused interrupt). It's more generalized than needed for our
    purpose.
    Fixes #97
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2025-09-20 Fix the argument order in test assertions
    [tests.cpp]
2025-09-20 Remove TODOs
    It's better to track them as an issue. It only confuses the reader.
2025-09-20 Remove the prototype
    We've done some changes to the source code that probably makes it
    incompatible now anyways, so it's better to go back in the git history
    if you want to use the prototype.
    [schema.fzz]
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2025-09-24 Added commands for 'timer play', 'timer pause', 'timer reset'
    [main.cpp]
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2025-09-30 Fixed a build problem on state_machine env.
    [main.cpp]
2025-09-30 Fixed a problem building render_timer_view env.
    [main.cpp]
2025-10-01 Fixed a bug in setup volume command.
    [main.cpp]
2025-10-01 Added setup buzzer on/off command.
    [main.cpp]
2025-10-02 Added test buzzer command.
    [main.cpp]
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2025-10-10 Remove redundant sketch
    The test cases already cover the counter, so the sketch itself doesn't
    serve a purpose anymore. There are several other sketches that offer
    similar and more complete examples.
    [main.cpp]
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2025-10-11 Make UART RX snappier
    Service the UART RX until it's empty.
    [main.cpp, tests.cpp]
2025-10-15 Fix crash when interacting with rotary knob during power-on
    Interrupts got fired before all callbacks were initialized, leading to
    undefined behavior - and crashes.
    A crash could occur with the following conditions:
    1. Power on the device
    2. Rotate the knob (this would mark the INT1 interrupt as pending),
    before `init_hw_rotary_encoder()` is executed.
    This would cause the rotation callback to be called with a null pointer.
    [main.cpp]
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2025-10-24 Fix merge mistake in 6e650ccfb2d0521309dad76019ef8619448701c0
    [tests.cpp]
2025-10-24 Switch to proper quadrature encoding
    This is far more reliant, and reduces the risk considerably of the
    rotary-encoder glitching in the end states.
2025-10-29 Implemented reboot fature using watchdog.
    Since the watchdog remains enabled after reboot, the bootloader needs to desable it before doing anything else.
    [main.cpp]
2025-11-10 Only link native tests with platform-independent code
    This way we get a lot better error messages in case we accidentally (or
    intentionally) include something from the atmega328 library.
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2025-11-12 Changes on the unit test
    Simplified the tests and put all the testing variables into a struct to make it easier to reset between tests.
    [tests.cpp]
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2025-11-30 Cosmetic fix to main
    [main.cpp]
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2026-03-04 Fix mistake in 23736b24c2f617866299bd969b5b6892af003ecd
    [tests.cpp]
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2026-03-11 Melody repeats until the timer RINGING resets to IDLE.
2026-03-11 Changed to reset_active_state_machine() when timer goes from RINGING to SET_TIME
2026-03-11 Fixed state machine test
    [tests.cpp]
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2026-04-01 Initialize battery measurement before starting it
    Fixes #165
2026-04-01 Remove the IDLE state
    Fixes #164
    [tests.cpp]
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2026-04-15 Fix menu wrap-around and add position indicator
    Agent-Logs-Url: https://github.com/emanuelen5/kitchen-timer/sessions/a9da42b7-342a-4bca-bd4b-768e94fc13d5
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2026-10-04 Report a pending single press before the rotation
    This fixes the failing test case.
    Pressing and releasing the button, and then rotating within the double press
    timeout, reported the rotation before the single press. On an idle timer, the
    rotation then set the time and the press started the timer, instead of the press
    doing nothing. This was easy to trigger when waking the timer from sleep.
    Flush the pending single press before reporting the rotation.
    [tests.cpp]
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

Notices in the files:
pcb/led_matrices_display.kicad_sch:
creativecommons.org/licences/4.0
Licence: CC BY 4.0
